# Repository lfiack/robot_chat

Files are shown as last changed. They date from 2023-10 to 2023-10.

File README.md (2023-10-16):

# robot_chat
My (as a prof) take at building a cat/mouse robot

## Make the project work
This project uses a submodule for the KiCAD library. To get it properly, use the `--recursive` option when cloning the repo :

```bash
git clone --recursive git@github.com:lfiack/robot_chat.git
```

If you forgot the `--recursive` option (as I do quite often), you can type the following command :

```bash
git submodule update --init --recursive
```

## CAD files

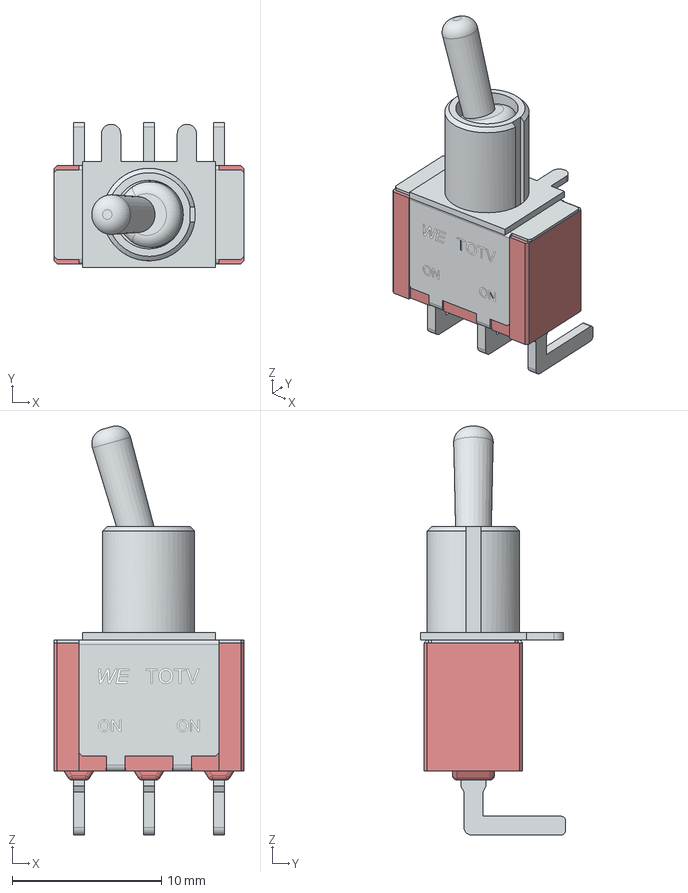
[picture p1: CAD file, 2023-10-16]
hardware/robot_chat/Toggle_Switch_472121020421/STP_472 121 020 421 (rev1).stp
12.7 x 9.72 x 27.4 mm
Base
Shielding
Switch
Pin x 3
Glue x 3
Shielding2

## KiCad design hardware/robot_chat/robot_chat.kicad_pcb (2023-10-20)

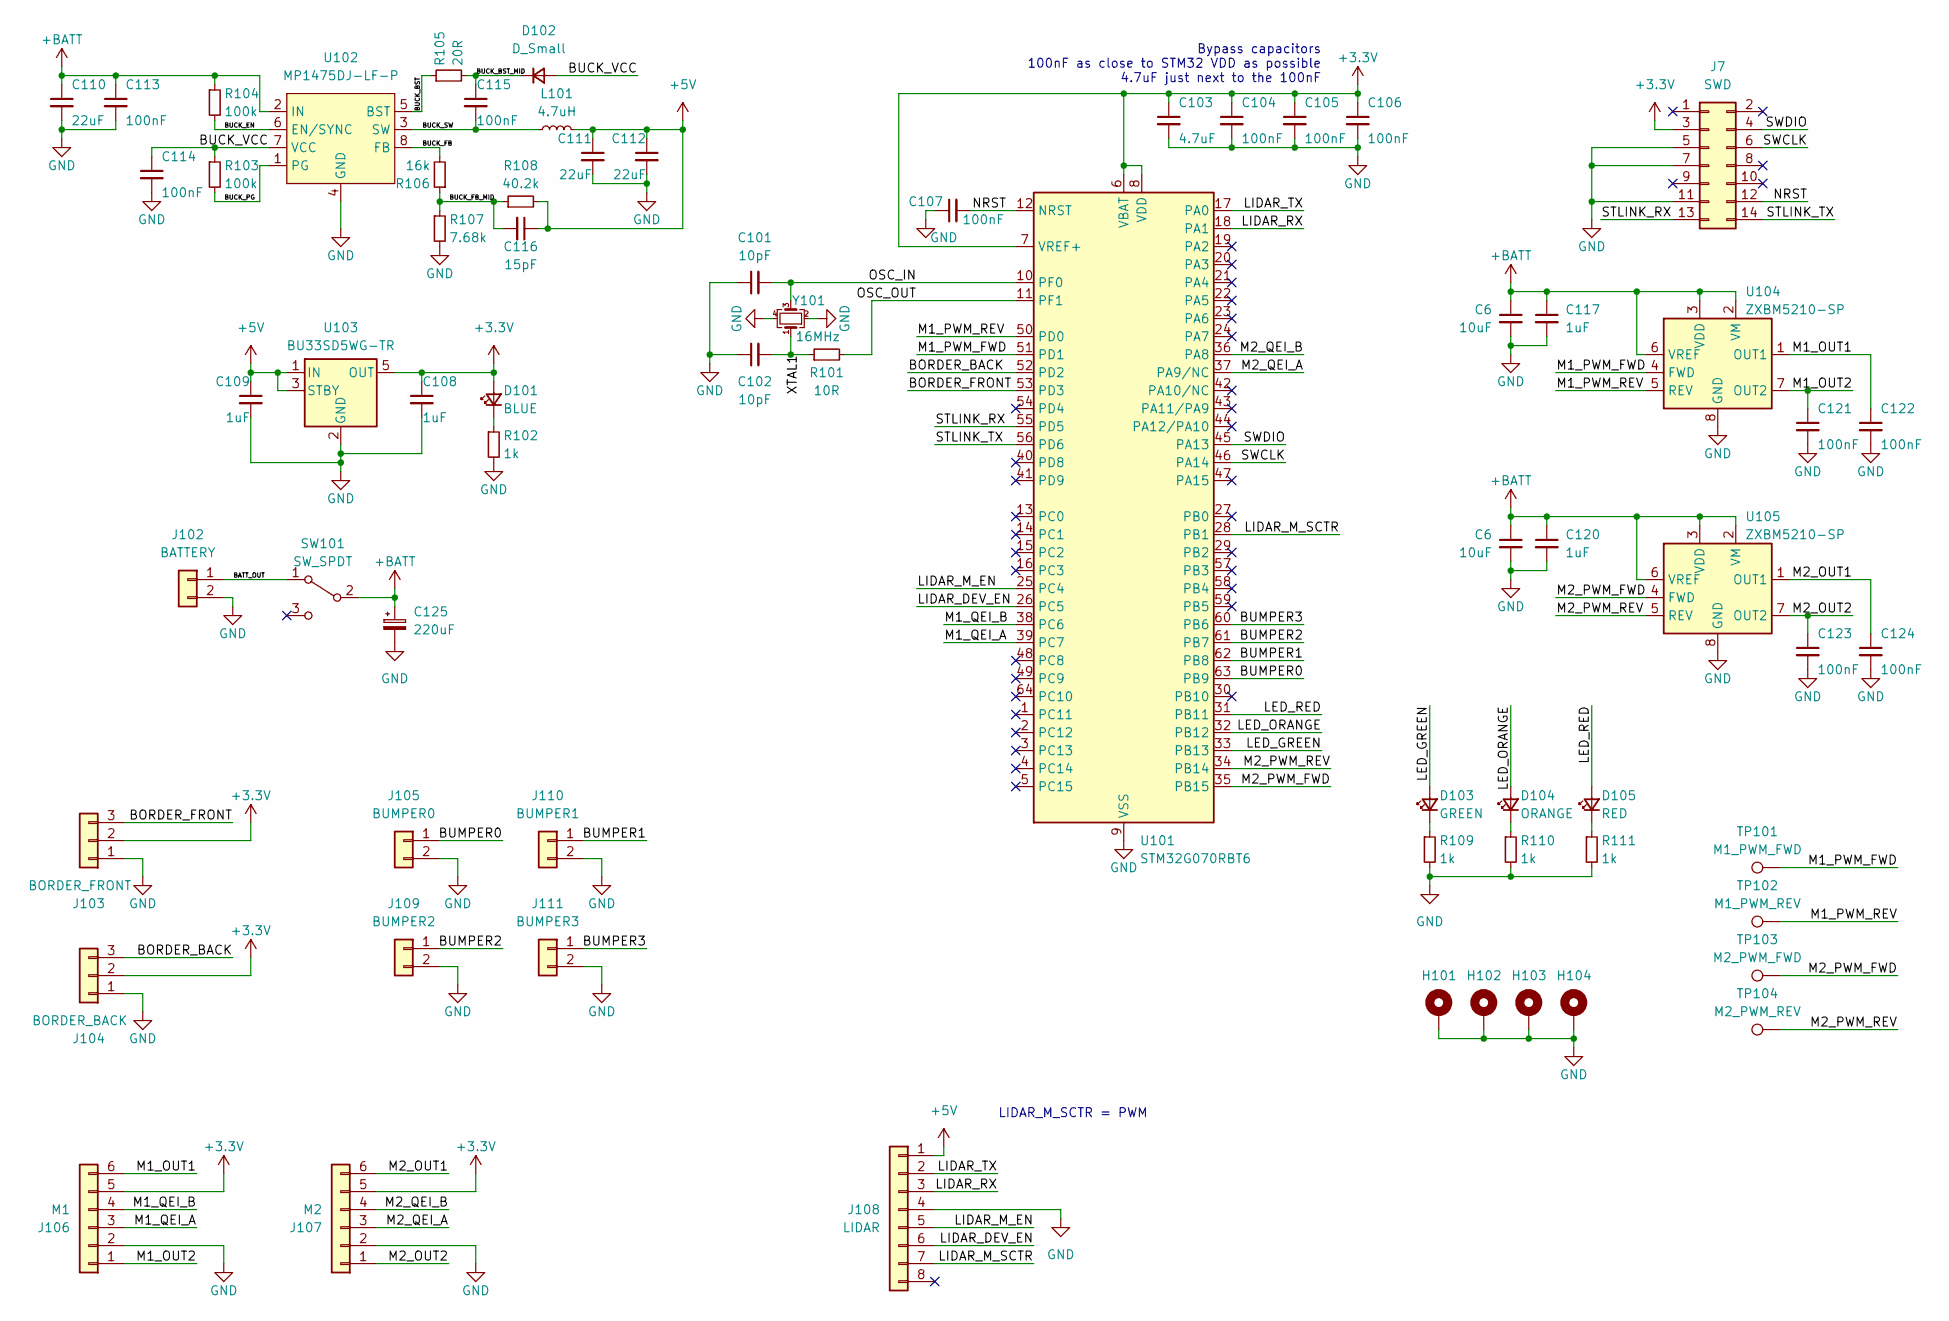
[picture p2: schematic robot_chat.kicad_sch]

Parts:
C6: 10uF; C_0603_1608Metric_Pad1.08x0.95mm_HandSolder; Farnell 2113070
C101, C102: 10pF; C_0603_1608Metric
C103: 4.7uF; C_0603_1608Metric
C104, C105, C106, C107, C113, C114, C115, C121, C122, C123, C124: 100nF; C_0603_1608Metric
C108, C109, C117, C120: 1uF; C_0603_1608Metric
C110, C111, C112: 22uF; C_0805_2012Metric
C116: 15pF; C_0603_1608Metric
C125: 220uF; CP_Elec_8x10.5
D101: BLUE; LED_0603_1608Metric
D102: D_Small; D_SOD-323
D103: GREEN; LED_0603_1608Metric
D104: ORANGE; LED_0603_1608Metric
D105: RED; LED_0603_1608Metric
H101, H102, H103, H104: MountingHole_Pad; MountingHole_3.2mm_M3_Pad_Via
J7: Conn_02x07_Odd_Even; PinHeader_2x07_P1.27mm_Vertical_SMD; Farnell 3226055
J102: BATTERY; JST_XH_S2B-XH-A_1x02_P2.50mm_Horizontal
J103: BORDER_FRONT; JST_XH_S3B-XH-A_1x03_P2.50mm_Horizontal
J104: BORDER_BACK; JST_XH_S3B-XH-A_1x03_P2.50mm_Horizontal
J105: BUMPER0; JST_XH_S2B-XH-A_1x02_P2.50mm_Horizontal
J106: M1; JST_XH_S6B-XH-A_1x06_P2.50mm_Horizontal
J107: M2; JST_XH_S6B-XH-A_1x06_P2.50mm_Horizontal
J108: LIDAR; JST_XH_S8B-XH-A_1x08_P2.50mm_Horizontal
J109: BUMPER2; JST_XH_S2B-XH-A_1x02_P2.50mm_Horizontal
J110: BUMPER1; JST_XH_S2B-XH-A_1x02_P2.50mm_Horizontal
J111: BUMPER3; JST_XH_S2B-XH-A_1x02_P2.50mm_Horizontal
L101: 4.7uH; L_1008_2520Metric; Farnell 2530076
R101: 10R; R_0603_1608Metric
R102, R109, R110, R111: 1k; R_0603_1608Metric
R103, R104: 100k; R_0603_1608Metric
R105: 20R; R_0603_1608Metric
R106: 16k; R_0603_1608Metric
R107: 7.68k; R_0603_1608Metric
R108: 40.2k; R_0603_1608Metric
SW101: SW_SPDT; Toggle_Switch
TP101: M1_PWM_FWD; TestPoint_Pad_D1.5mm
TP102: M1_PWM_REV; TestPoint_Pad_D1.5mm
TP103: M2_PWM_FWD; TestPoint_Pad_D1.5mm
TP104: M2_PWM_REV; TestPoint_Pad_D1.5mm
U101: STM32G070RBT6; LQFP-64_10x10mm_P0.5mm
U102: MP1475DJ-LF-P; TSOT-23-8
U103: BU33SD5WG-TR; SOT-23-5
U104, U105: ZXBM5210-SP; Diodes_SO-8EP
Y101: 16MHz; Crystal_SMD_EuroQuartz_MT-4Pin_3.2x2.5mm; Farnell 2853935

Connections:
+3.3V: C103.1, C104.1, C105.1, C106.1, C108.1, D101.2 (A), J7.3, J103.2, J104.2, J106.5, J107.5, U101.6 (VBAT), U101.7 (VREF+), U101.8 (VDD), U103.5 (OUT)
+5V: C109.1, C111.1, C112.1, C116.1, J108.1, L101.2, R108.2, U103.1 (IN), U103.3 (STBY)
+BATT: C6.1, C110.1, C113.1, C117.1, C120.1, C125.1, R104.1, SW101.2 (B), U102.2 (IN), U104.2 (VM), U104.3 (VDD), U104.6 (VREF), U105.2 (VM), U105.3 (VDD), U105.6 (VREF); also elsewhere on the board
/BATT_OUT: J102.1, SW101.1 (A)
/BORDER_BACK: J104.3, U101.52 (PD2)
/BORDER_FRONT: J103.3, U101.53 (PD3)
/BUCK_BST: R105.1, U102.5 (BST)
/BUCK_BST_MID: C115.1, D102.1 (K), R105.2
/BUCK_EN: R104.2, U102.6 (EN/SYNC)
/BUCK_FB: R106.2, U102.8 (FB)
/BUCK_FB_MID: C116.2, R106.1, R107.1, R108.1
/BUCK_PG: R103.2, U102.1 (PG)
/BUCK_SW: C115.2, L101.1, U102.3 (SW)
/BUCK_VCC: C114.1, D102.2 (A), R103.1, U102.7 (VCC)
/BUMPER0: J105.1, U101.63 (PB9)
/BUMPER1: J110.1, U101.62 (PB8)
/BUMPER2: J109.1, U101.61 (PB7)
/BUMPER3: J111.1, U101.60 (PB6)
/LED_GREEN: D103.2 (A), U101.33 (PB13)
/LED_ORANGE: D104.2 (A), U101.32 (PB12)
/LED_RED: D105.2 (A), U101.31 (PB11)
/LIDAR_DEV_EN: J108.6, U101.26 (PC5)
/LIDAR_M_EN: J108.5, U101.25 (PC4)
/LIDAR_M_SCTR: J108.7, U101.28 (PB1)
/LIDAR_RX: J108.3, U101.18 (PA1)
/LIDAR_TX: J108.2, U101.17 (PA0)
/M1_OUT1: C122.1, J106.6, U104.1 (OUT1)
/M1_OUT2: C121.1, J106.1, U104.7 (OUT2)
/M1_PWM_FWD: TP101.1, U101.51 (PD1), U104.4 (FWD)
/M1_PWM_REV: TP102.1, U101.50 (PD0), U104.5 (REV)
/M1_QEI_A: J106.3, U101.39 (PC7)
/M1_QEI_B: J106.4, U101.38 (PC6)
/M2_OUT1: C124.1, J107.6, U105.1 (OUT1)
/M2_OUT2: C123.1, J107.1, U105.7 (OUT2)
/M2_PWM_FWD: TP103.1, U101.35 (PB15), U105.4 (FWD)
/M2_PWM_REV: TP104.1, U101.34 (PB14), U105.5 (REV)
/M2_QEI_A: J107.3, U101.37 (PA9/NC)
/M2_QEI_B: J107.4, U101.36 (PA8)
/NRST: C107.2, J7.12, U101.12 (NRST)
/OSC_IN: C101.2, U101.10 (PF0), Y101.3
/OSC_OUT: R101.2, U101.11 (PF1)
/STLINK_RX: J7.13, U101.55 (PD5)
/STLINK_TX: J7.14, U101.56 (PD6)
/SWCLK: J7.6, U101.46 (PA14)
/SWDIO: J7.4, U101.45 (PA13)
/XTAL1: C102.2, R101.1, Y101.1
GND: C6.2, C101.1, C102.1, C103.2, C104.2, C105.2, C106.2, C107.1, C108.2, C109.2, C110.2, C111.2, C112.2, C113.2, C114.2, C117.2, C120.2, C121.2, C122.2, C123.2, C124.2, C125.2, H101.1, H102.1, H103.1, H104.1, J7.5, J7.7, J7.11, J102.2, J103.1, J104.1, J105.2, J106.2, J107.2, J108.4, J109.2, J110.2, J111.2, R102.2, R107.2, R109.2, R110.2, R111.2, U101.9 (VSS), U102.4 (GND), U103.2 (GND), U104.8 (GND), U104.9 (GND), U105.8 (GND), U105.9 (GND), Y101.2, Y101.4; also elsewhere on the board
unnamed: D101.1 (K), R102.1
unnamed: D103.1 (K), R109.1
unnamed: D104.1 (K), R110.1
unnamed: D105.1 (K), R111.1

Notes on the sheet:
Bypass capacitors 100nF as close to STM32 VDD as possible 4.7uF just next to the 100nF
LIDAR_M_SCTR = PWM

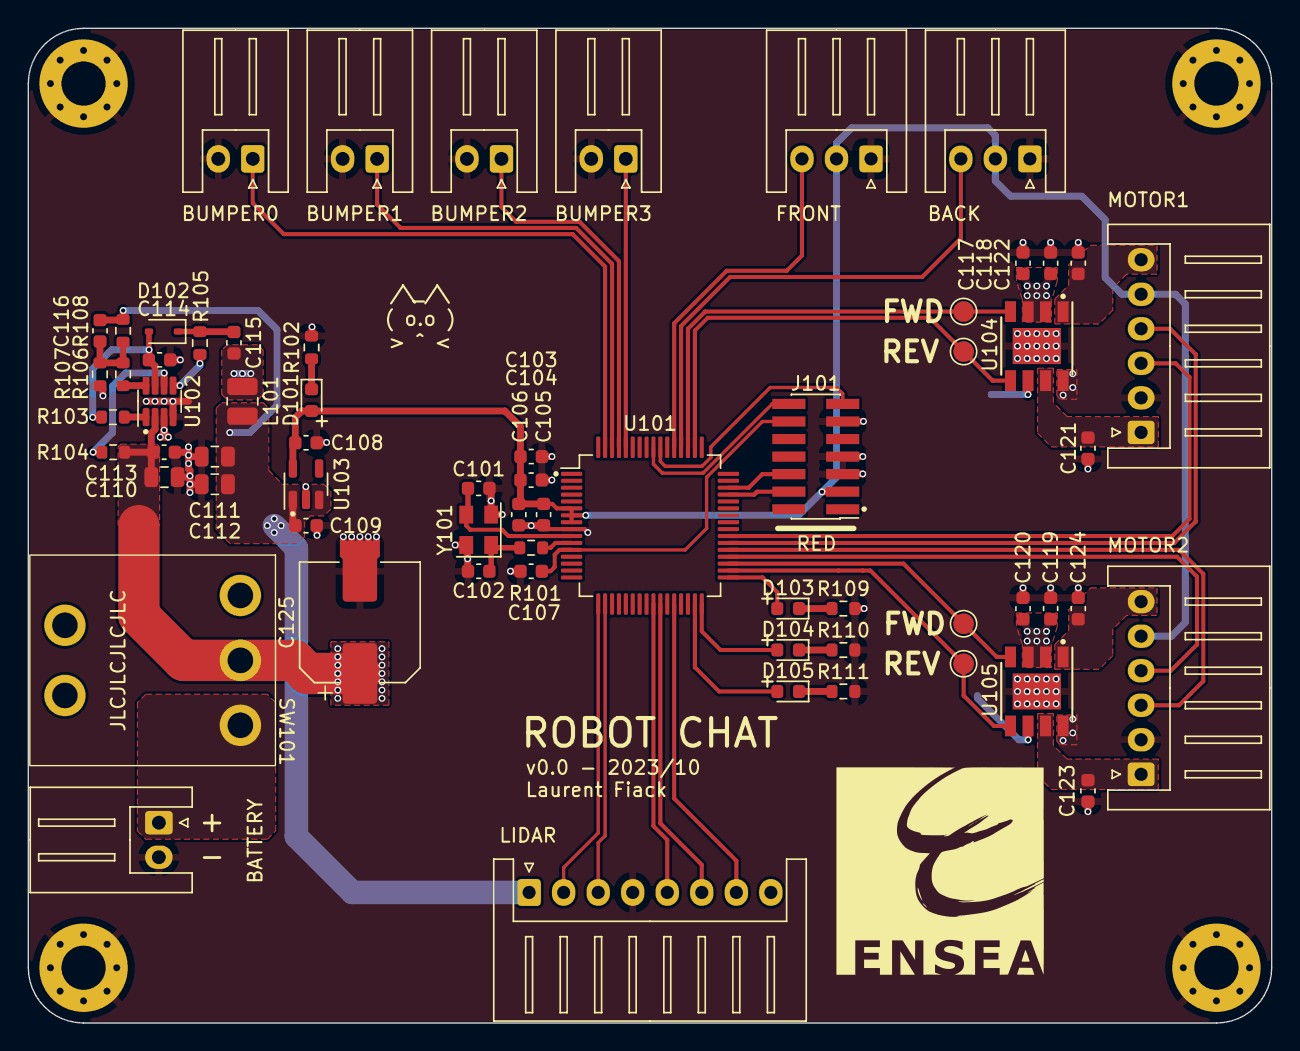
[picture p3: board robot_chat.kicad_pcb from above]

Board: 2 copper layers, 90.0 x 72.0 mm, 68 parts (0 on the bottom side), 51 nets.

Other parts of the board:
C6#2: 10uF; C_0603_1608Metric

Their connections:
+BATT: C6#2.1; also elsewhere on the board
GND: C6#2.2; also elsewhere on the board

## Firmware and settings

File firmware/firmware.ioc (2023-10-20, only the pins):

Mcu.UserName=STM32G070RBTx
PA0.Signal=USART4_TX
PA1.Signal=USART4_RX
PA13.Signal=SYS_SWDIO
PA14-BOOT0.Signal=SYS_SWCLK
PA8.GPIO_Label=M1_QEI_B
PA8.Signal=S_TIM1_CH1
PA9.GPIO_Label=M1_QEI_A
PA9.Signal=S_TIM1_CH2
PB1.GPIO_Label=LIDAR_PWM
PB1.Signal=S_TIM14_CH1
PB11.Signal=GPIO_Output
PB12.Signal=GPIO_Output
PB13.Signal=GPIO_Output
PB14.GPIO_Label=M1_PWM_FWD
PB14.Signal=S_TIM15_CH1
PB15.GPIO_Label=M1_PWM_REV
PB15.Signal=S_TIM15_CH2
PB6.Signal=GPXTI6
PB7.Signal=GPXTI7
PB8.Signal=GPXTI8
PB9.Signal=GPXTI9
PC4.Signal=GPIO_Output
PC5.Signal=GPIO_Output
PC6.GPIO_Label=M2_QEI_B
PC6.Signal=S_TIM3_CH1
PC7.GPIO_Label=M2_QEI_A
PC7.Signal=S_TIM3_CH2
PD0.GPIO_Label=M2_PWM_FWD
PD0.Signal=S_TIM16_CH1
PD1.GPIO_Label=M2_PWM_REV
PD1.Signal=S_TIM17_CH1
PD2.Signal=GPXTI2
PD3.Signal=GPXTI3
PD5.Signal=USART2_TX
PD6.Signal=USART2_RX

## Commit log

2023-10-16 kicad lib + README
2023-10-16 started schematic
    [robot_chat.kicad_pcb, robot_chat.kicad_sch]
2023-10-19 place + started routing
    [robot_chat.kicad_pcb, robot_chat.kicad_sch]
